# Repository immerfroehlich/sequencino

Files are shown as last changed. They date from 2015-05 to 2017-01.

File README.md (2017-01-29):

Sequencino
============================================================
The project is inspired by SimplenZAR.
http://www.roebbeling.de/wordpress/?p=85
But with a different requirement.

The goal is to record a sequence through
your midi controller and vary the tempo
and pauses in between the notes.

The hardware schematic is based upon the fritzing
sketch of SimplenZAR:
http://www.roebbeling.de/wordpress/wp-content/uploads/2011/02/simplenZAR.fz_.zip
But that is only temporary.
The midi input schematic is based upon the "Send and Receive MIDI with Arduino"
instructable tutorial by amandaghassaei:
http://www.instructables.com/id/Send-and-Receive-MIDI-with-Arduino/?ALLSTEPS
And the Arudino schematic is based upon the "Arduino on a breadboard" article
https://www.arduino.cc/en/Main/Standalone but without the power regulation
and the usb to serial modules, because the power comes from a regulated
power supply already.

Fritzing can be downloaded here:
http://fritzing.org/download/

This project uses Eclipse Arduino IDE, because the original
Arduino IDE does not work for a project beyond a 
few simple Arduino basics.

Download V2.3 here:
http://eclipse.baeyens.it/download.php
And Arduino 1.5.x here:
http://arduino.cc/en/Main/Software

Another Needed Infos
========================================
To burn the Arduino bootloader to your Atmega 328P- PU
you need the following Sketch:
https://github.com/WestfW/OptiLoader
Use the Layout from https://www.arduino.cc/en/Tutorial/ArduinoToBreadboard (with external Clock!)

Recipe
========================================
TODO: Tranlation needed

For Arduino Module
------------------
- 1x Atmel Atmega 328P- PU, DIL-28 (http://www.reichelt.de/Atmel-ATMega-AVRs/ATMEGA-328P-PU/3/index.html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)
- 1x 1N 4148 Schaltdiode 100V, 0,15A (http://www.reichelt.de/1N-UF-AA-Dioden/1N-4148/3/index.html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)
- 2x Kerko 22P Kondensator (http://www.reichelt.de/Scheiben/KERKO-22P/3/index.html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)
- Standard- Quarz 16 MHz HC49/U-S (http://www.reichelt.de/Quarze/16-0000-HC49U-S/3/index.html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)

For controller module
----------------------
- 2x Taster Fritzing Starter Kit
- 2x Drehwiderstand Fritzing Starter Kit
- Widerstände (Resistors)

For midi modules
----------------------
- 2x DIN Midi Stecker
- 1x Optokoppler 6N 138, DIP 8 (http://www.reichelt.de/Optokoppler/6N-138/3/index.html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)
- Diode 1N 4148 (http://www.reichelt.de/1N-UF-AA-Dioden/1N-4148/3/index.html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)

Anything else
----------------------
- 1x Lumberg Einbaukupplung DIN45323 (http://www.reichelt.de/Hohlstecker/LUM-NEB-1R/3/index.html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)
- Kabel (Litze) 0,22^2, 4x5m (http://www.pollin.de/shop/dt/MTI2OTkxOTk-/Haustechnik/Kabel_Draehte_Litzen/Litzen/Litzen_Sortiment_0_22_mm_4x_5_m.html)

Optional (for the ease of use)
----------------------
- 1x GS 28-S :: IC-Sockel, 28-polig, doppelter Federkontakt (http://www.reichelt.de/IC-Sockel/GS-28-S/3/index.html?ACTION=3&GROUPID=7429&ARTICLE=86281&OFFSET=500&)

Relase Notes
=======================
Version 1.0.0:
----------------
Finished working single track recording and playback with tempo poti.

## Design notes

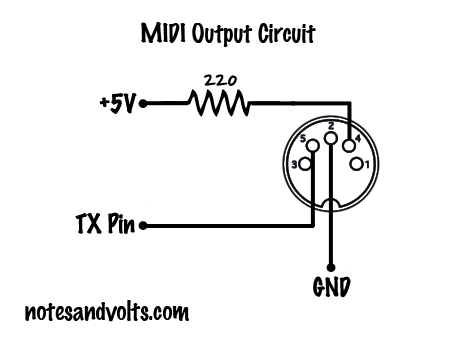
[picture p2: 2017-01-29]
schematic/SCHEMATIC_Midi_Output.png

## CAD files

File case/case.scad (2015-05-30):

$fn = 100;

//Measurement is defined in millimeters

printerTolerance = 0.6;
ledRadius = 2.5;
potiRadius = 2.55;
buttonXY = 6;

caseWidth = 120;
caseDepth = 50;
caseHeight = 30;

wallThickness = 5;
inlayThickness = 2.5;
inlayHighness = 5;

midiX = 21.2;
midiZ = 19.5; //y in Draufsicht
midiDistance = 15;

topCase();
//buttomCase();

module buttomCase() {
	buttomZ = 20;

	roomX = caseWidth - (2 * wallThickness);
	roomY = caseDepth - (2 * wallThickness);

	difference(){
		cube([caseWidth, caseDepth, buttomZ]);

		translate([wallThickness, wallThickness, -wallThickness]) {
			cube([roomX, roomY, buttomZ]);
		}

		buttomCaseOuterInlay();
	}
}

module buttomCaseOuterInlay() {
	roomX = caseWidth - (2 * inlayThickness);
	roomY = caseDepth - (2 * inlayThickness);
	
	difference(){
		translate([-0.5, -0.5, -1]) {
			cube([caseWidth+1, caseDepth+1, inlayHighness + 1]);
		}

		translate([inlayThickness, inlayThickness, -1.5]) {
			cube([roomX, roomY, (inlayHighness + 1 + 1)]);
		}
	}
}

module topCase() {
	difference() {
		case();

		positionedMidiPanel();

		translate([25, 35, 20]){
			ledBoard();
		}

		translate([25, 15, 27.5]){
			button();
		}

		translate([95, 15, 27.5]){
			button();
		}

		translate([50, 15, 20]) {
			poti();
		}

		translate([70, 15, 20]) {
			poti();
		}
	}
}

module case() {
	roomX = caseWidth - (2 * wallThickness);
	roomY = caseDepth - (2 * wallThickness);
	roomZ = caseHeight;

	inlayX = caseWidth - (2 * inlayThickness);
	inlayY = caseDepth - (2 * inlayThickness);
	inlayZ = inlayHighness;

	difference() {
		cube([caseWidth, caseDepth, caseHeight]);

		translate([wallThickness, wallThickness, -wallThickness]) {
			cube([roomX, roomY, roomZ]);
		}

		translate([inlayThickness, inlayThickness, -1]) {
			cube([inlayX, inlayY, (inlayZ + 1)]);
		}
	}
}

module positionedMidiPanel() {
	midiPanelWidth = 2 * midiX + midiDistance + 2 * printerTolerance;
	xOffset = (caseWidth - midiPanelWidth) / 2;
	yOffset = caseDepth - wallThickness - 0.5;
	
	translate([xOffset, yOffset, -1]) {
		midiPanel();
	}
}

module midiPanel() {
	midi();

	distance = midiX + midiDistance + printerTolerance;

	translate([distance, 0, 0]) {
		midi();
	}
}

module midi() {
	height = caseHeight - wallThickness + 1;
	y = wallThickness + 1;
	cube( size=[(midiX + printerTolerance), y, height]);
}

module button() {
	cube( (buttonXY + printerTolerance), center=true);
}

module poti() {
	cylinder(h=15, r=(potiRadius + printerTolerance) );
}

module ledBoard() {
	for (i=[0: 10: 70]) {
		translate([i, 0, 0]) {
			led();
		}
	}
}

module led() {
	cylinder(h=15, r=(ledRadius + printerTolerance) );
}

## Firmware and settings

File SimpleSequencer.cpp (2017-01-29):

// Do not remove the include below
#include "SimpleSequencer.h"
#include "StopWatch.h"
#include "Sequence.h"
#include "MIDI.h"
#include "AnalogMomentaryPushButton.h"

MIDI_CREATE_DEFAULT_INSTANCE();

StopWatch stopwatch = StopWatch();

Sequence tracks[4];

int step = 7;
int maxSteps = 7;
int state = 2; //1=record; 2=playback

const int stepLed1 = 6;
const int stepLed2 = 7;
const int stepLed3 = 8;
const int stepLed4 = 9;
const int stepLed5 = 10;
const int stepLed6 = 11;
const int stepLed7 = 12;
const int stepLed8 = 13;

const int playLed = 3;
const int recordLed = 4;
const int modeLed3 = 5;

const int tempoPoti = A2; // Analog A2
int tempoPotiPosition;

const int recordButton = A1;

AnalogMomentaryPushButton playButton;

void setup() {
	// set the digital pin for the 8 step leds
	pinMode(stepLed1, OUTPUT);
	pinMode(stepLed2, OUTPUT);
	pinMode(stepLed3, OUTPUT);
	pinMode(stepLed4, OUTPUT);
	pinMode(stepLed5, OUTPUT);
	pinMode(stepLed6, OUTPUT);
	pinMode(stepLed7, OUTPUT);
	pinMode(stepLed8, OUTPUT);

	pinMode(playLed, OUTPUT);
	pinMode(recordLed, OUTPUT);
	pinMode(modeLed3, OUTPUT);

	pinMode(tempoPoti, INPUT);

	playButton.initialize(A0);
	pinMode(recordButton, INPUT);

	MIDI.begin();
}



/**
 * LED and counter
 **/

void nextLed(int currentStep, int lastStep) {

	int ledOffset = stepLed1;

	int lastLed = (currentStep % 8) + ledOffset;
	int led;
	if(currentStep == lastStep) {
		led = ledOffset;
	}
	else {
		led = ( (currentStep + 1) % 8 ) + ledOffset;
	}

	digitalWrite(lastLed, LOW);
	digitalWrite(led, HIGH);
}

void sendMidiCommand(struct MidiCommand command) {
	MIDI.send(command.command, command.param1, command.param2, 1);
}

void sendMidiAllSoundOff() {
	MIDI.sendControlChange(midi::AllSoundOff, 0, 1);
}

void nextStep() {
	if(state == 1) { //record
		step++;
		maxSteps++;
	}
	else {
		//TODO Durch step++ und if(step > maxSteps) step = 0; ersetzten
		//um ggf den modulo overflow zu beseitigen.
		step = (step + 1) % (maxSteps + 1);
	}
}

void resetRecordState() {
	step = -1;
	maxSteps = -1;
	state = 1; //record
}

void resetPlaybackState() {
	step = 0;
	state = 2; //playback
}

boolean playState = false;
boolean recordState = false;
boolean lastPlayButtonState = false;
boolean lastRecordButtonState = false;

void loop(){
	
	boolean recordPressed = analogRead(recordButton) > 500 ? true : false;
	//boolean recordPressed = digitalRead(recordButton);  
	if(playButton.isToggled()) {
		playState = !playState;
		recordState = false;
		digitalWrite(recordLed, LOW);
		digitalWrite(playLed, HIGH);
		resetPlaybackState();

		sendMidiAllSoundOff();

		//In HardwareSerial.cpp old flush method cleared the uart buffer
		//_rx_buffer->head = _rx_buffer->tail;
	}
	if(recordPressed && (recordPressed != lastRecordButtonState)) {
		recordState = !recordState;
		playState = false;
		digitalWrite(playLed, LOW);
		digitalWrite(recordLed, HIGH);
		resetRecordState();
		stopwatch.reset();
		stopwatch.start();

		sendMidiAllSoundOff();
	}
	lastRecordButtonState = recordPressed;

	if(playState) {
		play();
	}
	else if(recordState) {
		record();
	}
	else { //Stop State
		midiThrough();
	}
}

void midiThrough() {
	//Midi through is a configuration in the MIDI library
	MIDI.read();

//	if(Serial.available() > 2) {
//		Serial.write(Serial.read());
//		Serial.write(Serial.read());
//		Serial.write(Serial.read());
//	}
}

void record(){
	if (MIDI.read()) {               // Is there a MIDI message incoming ?
		if(MIDI.getType() != midi::NoteOn && MIDI.getType() != midi::NoteOff) {
			return;
		}
		unsigned int length = stopwatch.elapsed();
		nextStep();

		//Just debug stuff
		digitalWrite(stepLed1, HIGH);
		delay(100);
		digitalWrite(stepLed1, LOW);

		//Wird das hier erzeugte MidiCommand wieder aufgeräumt?
		MidiCommand command = {MIDI.getType(), MIDI.getData1(), MIDI.getData2(), length};
		tracks[0].setStep(step, command);
		stopwatch.reset();
		stopwatch.start();

		//sendMidiCommand(command);
	}
}

/**
 * Play
 **/
void play() {
	int potiValue = analogRead(tempoPoti);
	unsigned int calculatedDelay = calcDelay(potiValue);


	if(stopwatch.isRunning() && calculatedDelay > stopwatch.elapsed()) {
		//Serial.write(" StopWatch Hold ");
		return;
	}
	MidiCommand command = tracks[0].getStep(step);

	//nextLed(currentStep, lastStep);
	//int sequenceStep = currentStep * 2;
	nextStep();
	stopwatch.reset();
	stopwatch.start();

	//Serial.write("Write Command");
	sendMidiCommand(command);
	//Serial.write(currentStep);
}

int calcDelay(int potiValue) {
	return map(potiValue, 0, 1023, 20, 500);

	//40 * log(x*10) -160
	//int returnVal = 40 * log(potiValue*10+50) - 160;
	//return returnVal < 0 ? 0 : returnVal;


	//  int potiPercent = ((float)potiValue / (float)1023) * 100;
	//
	//  int tempoValue = (1000 / 100) * potiPercent + 50;
	//  return tempoValue;
}

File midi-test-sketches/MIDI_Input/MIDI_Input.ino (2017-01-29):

#include <MIDI.h>  // Add Midi Library

#define LED 13    // Arduino Board LED is on Pin 13

//Create an instance of the library with default name, serial port and settings
MIDI_CREATE_DEFAULT_INSTANCE();

void setup() {
  pinMode (LED, OUTPUT); // Set Arduino board pin 13 to output
  MIDI.begin(MIDI_CHANNEL_OMNI); // Initialize the Midi Library.
  // OMNI sets it to listen to all channels.. MIDI.begin(2) would set it 
  // to respond to notes on channel 2 only.
  MIDI.setHandleNoteOn(MyHandleNoteOn); // This is important!! This command
  // tells the Midi Library which function you want to call when a NOTE ON command
  // is received. In this case it's "MyHandleNoteOn".
  MIDI.setHandleNoteOff(MyHandleNoteOff); // This command tells the Midi Library 
  // to call "MyHandleNoteOff" when a NOTE OFF command is received.
}

void loop() { // Main loop
  MIDI.read(); // Continuously check if Midi data has been received.
}

// MyHandleNoteON is the function that will be called by the Midi Library
// when a MIDI NOTE ON message is received.
// It will be passed bytes for Channel, Pitch, and Velocity
void MyHandleNoteOn(byte channel, byte pitch, byte velocity) { 
  digitalWrite(LED,HIGH);  //Turn LED on
}

// MyHandleNoteOFF is the function that will be called by the Midi Library
// when a MIDI NOTE OFF message is received.
// * A NOTE ON message with Velocity = 0 will be treated as a NOTE OFF message *
// It will be passed bytes for Channel, Pitch, and Velocity
void MyHandleNoteOff(byte channel, byte pitch, byte velocity) { 
  digitalWrite(LED,LOW);  //Turn LED off
}

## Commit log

2015-01-11 Added fritzing schema for the project
    [sequencino.fzz]
2015-01-25 Corrected input schema
    [sequencino.fzz]
2015-05-15 Fixed playing and recording. Some Midi Command frames have less then 3 bytes.
    [SimpleSequencer.cpp]
2015-05-17 Added a OpenSCAD file for the case.
    [case.scad]
2015-05-20 Changed dimensions to milimeters.
    [case.scad]
2015-05-20 Added potis and buttons to the case.
    [case.scad]
2015-05-30 Added Midi connectors and parametrized some methods
    [case.scad]
2015-05-30 Added a buttom case.
    [case.scad]
2015-07-27 Updated schematic to use a standalone atmega 328P
    [sequencino.fzz]
2015-12-26 Added infos about midi input circuit.
2015-12-26 Added info about midi input circuit.
2016-01-31 Milestonegit status! Recording and playback is at least working. But with timing problems.
    [SimpleSequencer.cpp]
2016-01-31 Corrected timing problems by deleting debug led. SoundOff on state change.
    [SimpleSequencer.cpp]
2016-10-13 Added array for sequences - multi track.
2017-01-29 Added button classes. Added array of Sequences.
